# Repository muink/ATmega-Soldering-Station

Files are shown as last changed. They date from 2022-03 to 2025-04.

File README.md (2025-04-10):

## !!! Warning: the version with "t" is the test version, there may be stability problems! Not recommended for production environments
## !!! 警告：带有“t”的是测试版本，可能存在稳定性问题！不建议用于生产环境

# 1. Overview
T12 焊台控制器功能介绍
T12 Quick Heating Soldering Station featuring
- 烙铁头温度实时监测
- Temperature measurement of the tip
- PID温度控制
- Direct or PID control of the heater
- 可以通过编码器进行控制温度
- Temperature control via rotary encoder
- 短按编码器进入短时升温模式
- Boost mode by short pressing rotary encoder switch
- 长按编码器进入主菜单
- Setup menu by long pressing rotary encoder switch
- 手柄震动检测（需要手柄含有震动传感器）
- Handle movement detection (by checking ball switch)
- 烙铁上架检测（使用红外距离传感器）
- Handle docked detection (by IR distance sensor)
- 手柄连接检测（通过判断烙铁头温度是否能够被读取来实现）
- Iron unconnected detection (by idenfying invalid temperature readings)
- 定时器设定 - 随眠，关机时间
- Time driven sleep/power off mode if iron is unused (movement detection)
- 可以测量主控芯片电压以及温度
- Measurement of input voltage, Vcc and ATmega's internal temperature
- 在OLED上实现信息显示
- Information display on OLED
- 支持无源蜂鸣器
- Buzzer
- 允许设置不同烙铁头的温度校准值
- Calibrating and managing different soldering tips
- 设置被保存在EEPROM，掉电不丢失
- Storing user settings into the EEPROM
- 允许热插拔烙铁头，并弹出烙铁头配置选择菜单
- Tip change detection
- 支援 N-沟道和 P-沟道 MOS管
- Support for N-Channel and P-Channel MOSFETs
- 支持屏幕翻转
- Screen flip support
- 支持编码器反转
- Rotary encoder reverse support

## =========UI upgraded version =========

- 芯片过热以及低电压报警
- Chip overheating and low voltage alarm
- 更好的实时温度条以及实时功率条
- Better real-time temperature bar and real-time power bar
- 拥有过渡动画
- Have transition animation
- 内置屏幕保护程序
- Built in screen saver
- 屏幕翻转设置
- Screen flip settings
- 内置英文、中文语言包
- Built in English and Chinese language pack
- 开机密码设置
- System Password
- 允许设置旋钮方向
- Knob direction setting menu
- 内嵌看门狗，宕机自动重启
- Watchdog timer automatic reset the MCU

## V1.8t7 New features:

- EEPROM可用性检查机制
- EEPROM availability check

- 允许保存最大30个烙铁头的配置
- Tip change detection30 preservable soldering tip configurations

- 9段温度曲线拟合
- 9 segments of temperature curve fitting

## Links:
- Project Link: https://easyeda.com/dropair/z-solderingstation-smd-v2_copy
- Project Video (Orignal): https://youtu.be/I9ATDxvQ1Bc
- Video from John Glavinos (electronics4all): https://youtu.be/4YDcWfOQmz4
- Video from LHW-createskyblue (UI-v1.6L): https://b23.tv/LiOe54
- T245 version with P-channel MOSFET by TaaraLabs: https://taaralabs.eu/atmega-t245/

# 2. Versions, Upgrades and Notes

## Soldering Station v2.8:

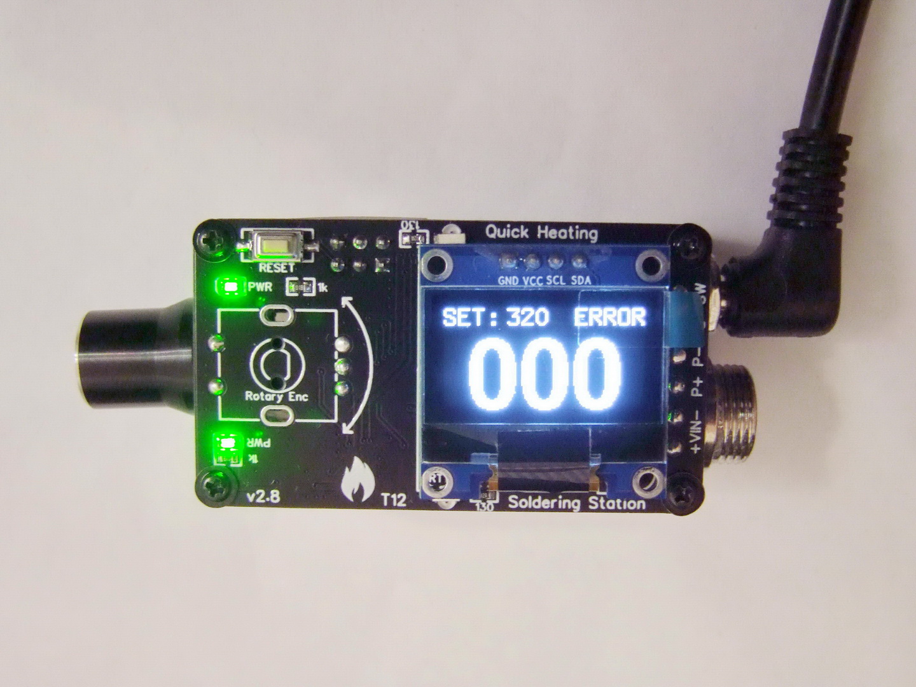
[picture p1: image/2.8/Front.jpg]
Front

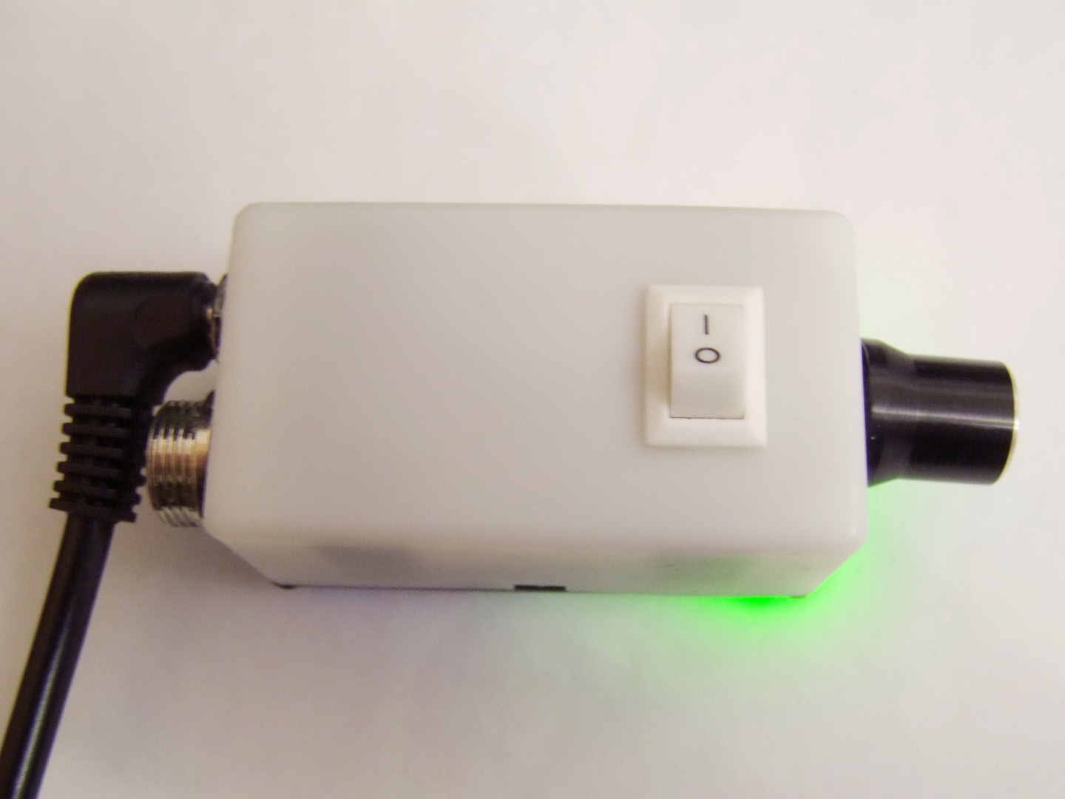
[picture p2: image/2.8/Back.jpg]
Back

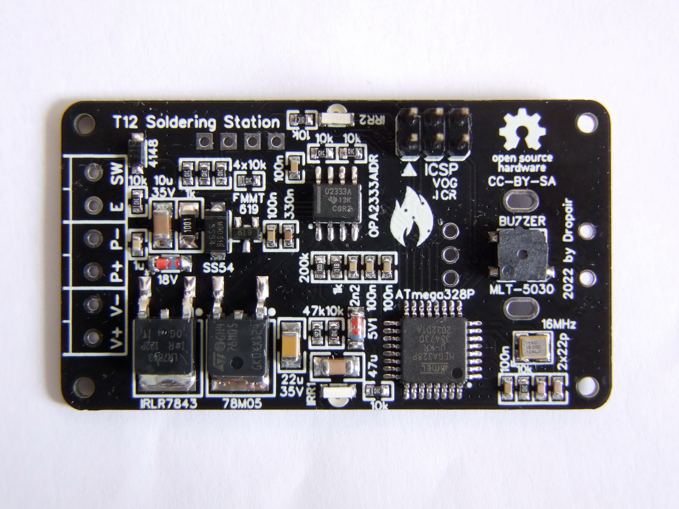
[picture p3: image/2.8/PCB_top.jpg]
PCB_Top

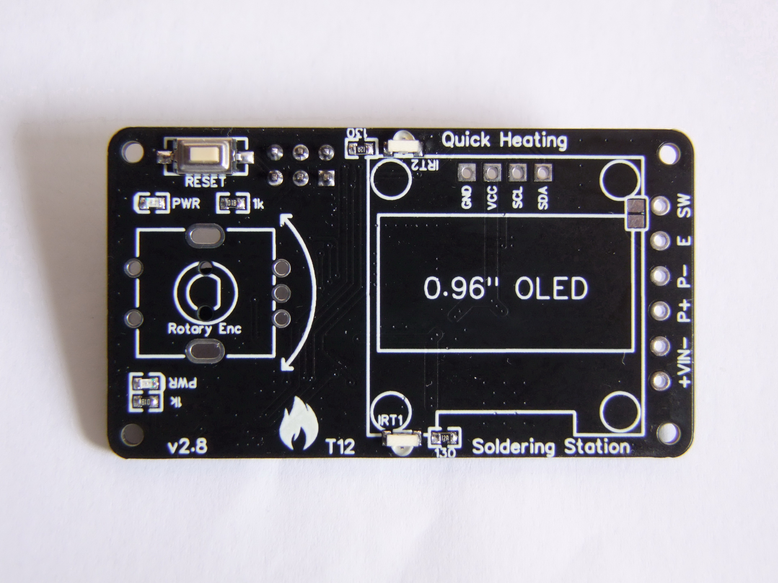
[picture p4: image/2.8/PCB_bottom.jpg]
PCB_Bottom

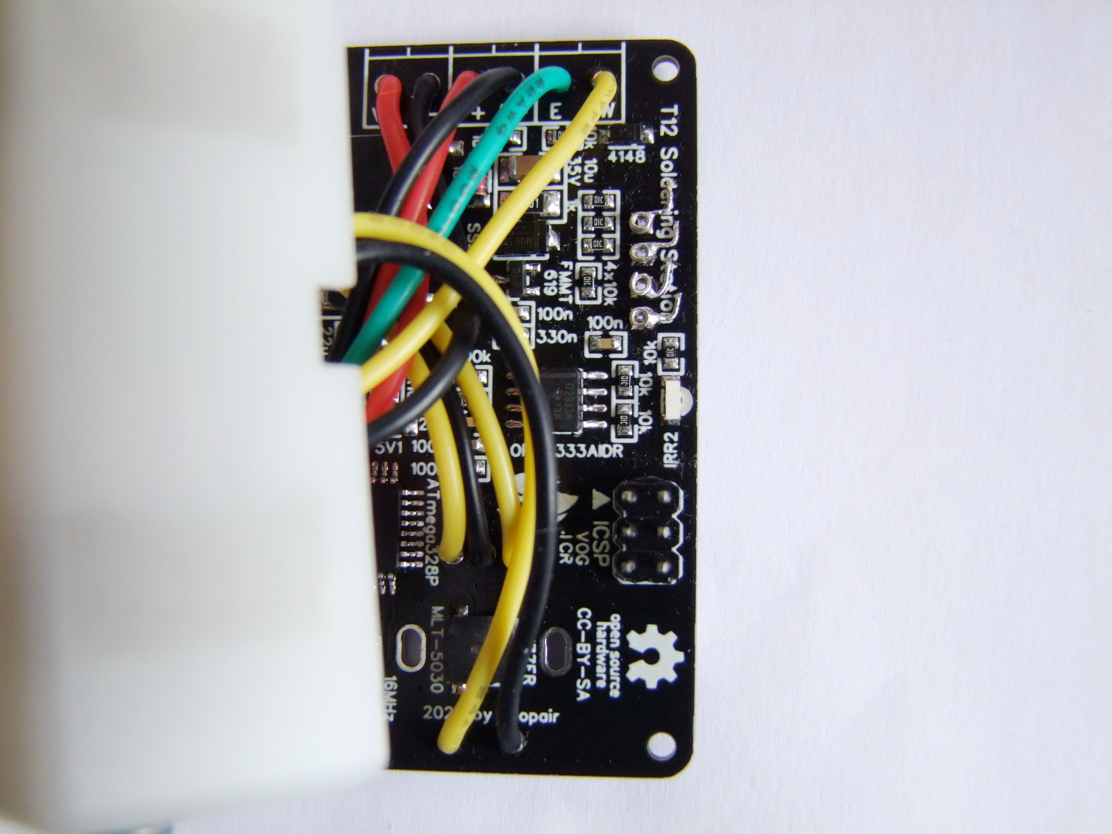
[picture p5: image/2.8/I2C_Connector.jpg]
I2C_Connector


## UI-V1.8t6 UI Upgrade by createskyblue & lihaoyun6



### Default control interface



### EEPROM availability check



### Tip menu



### 9 segments of temperature curve fitting & Soldering tip calibration page



### Temperature calibration coefficient



### Encoder direction regulation

Video from LHW-createskyblue (UI-v1.6L): https://b23.tv/LiOe54
	






## Notes and Errors

- In the board version 2.5 the diode D1 may overheat. To be on the safe side, the 18V zener diode D4 should be removed and the soldering station should be operated with a maximum of 20V. Alternatively, the diode D1 can be replaced with an SS54 schottky diode and the BJT Q1 with an FMMT619. 

# 3. Power Supply Specification Requirements #

Choose a power supply with an output voltage between 12V and 24V which can provide an output current according to the table below. The power supply must be well stabilized. The current and power is determined by the resistance (R = 8 Ohm) of the heater.

|Voltage (U)|Current (I) = U / R|Power (P) = U² / R|
|-|-|-|
|12 V|1.50 A|18 W|
|13 V|1.63 A|21 W|
|14 V|1.75 A|25 W|
|15 V|1.88 A|28 W|
|16 V|2.00 A|32 W|
|17 V|2.13 A|36 W|
|18 V|2.25 A|41 W|
|19 V|2.38 A|45 W|
|20 V|2.50 A|50 W|
|21 V|2.63 A|55 W|
|22 V|2.75 A|61 W|
|23 V|2.88 A|66 W|
|24 V|3.00 A|72 W|

# 4. Temperature Measurement and OpAmp Considerations #

A thermocouple (temperature sensor) is located in the T12 soldering tip. It creates a very small voltage depending on the temperature difference between the hot end and the cold junction (about 22 microvolts per degree Celsius). To measure this, the heater must be switched off since both share the same connections. The low voltage is amplified by the OpAmp and measured by the ADC of the microcontroller. The LMV358 is a very cheap and versatile OpAmp, but not the ideal choice for this task because it has a fairly high input offset voltage and is quite noisy. Although the SolderingStation also works with this OpAmp thanks to the software's smoothing and calibration algorithms, I highly recommend spending a little more money in a better one. The OPA2330AIDR or OPA2333AIDR for instance have the same pinout and can also be used with this board. They provide significantly more accurate and stable temperature measurements.






# 5. Heater High Side Switch with N-Channel MOSFET and Charge Pump #

The microcontroller switches the heater on and off via the MOSFET. Since the temperature measurement must be done over the same line and against ground, the MOSFET has to be placed between the supply voltage and the heater (high-side switch). A P-Channel MOSFET is normally used for this configuration. However, N-Channel MOSFETs usually have a lower resistance (RDS (on)), in the case of the IRLR7843 only 3 milliohms. A low resistance means a higher efficiency and a lower heat development of the MOSFET. For an N-channel MOSFET to function as a high-side switch, an additional circuit is required to maintain a positive GATE-TO-SOURCE voltage after the MOSFET is switched on. This is done using a so-called charge pump consisting of a capacitor and a diode. The principle of operation is illustrated in the following graphic by [Smallp Tsai](https://github.com/SmallpTsai):




# 6. Building Instructions #

In addition to the components for the PCB you will need the following:

- 3D-printed case ***1**
- SSD1306 0.96inch IC2 OLED ***1**
- EC11 Rotary encoder ***1**
- GX12-4P Aviator Plug ***1**
- DC-5.5*2.1 Power Jack ***1**
- KCD11 Rocker Switch ***1**
- 22AWG Wires(Red/Black/Green) **~~**
- 24AWG Wires(Black/Yellow) **~~**
- Heat Shrink Tube **~~**
- 20x10x2mm Neodymium Magnets ***4**
- M2x5mm Self-tapping screws ***4**

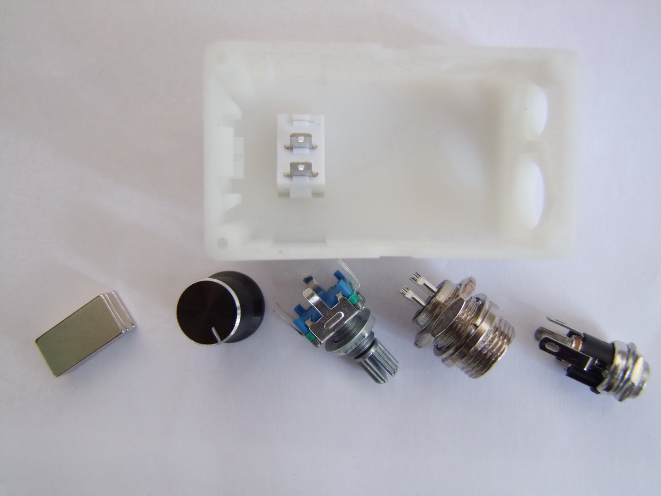
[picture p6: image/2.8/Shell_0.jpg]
Parts

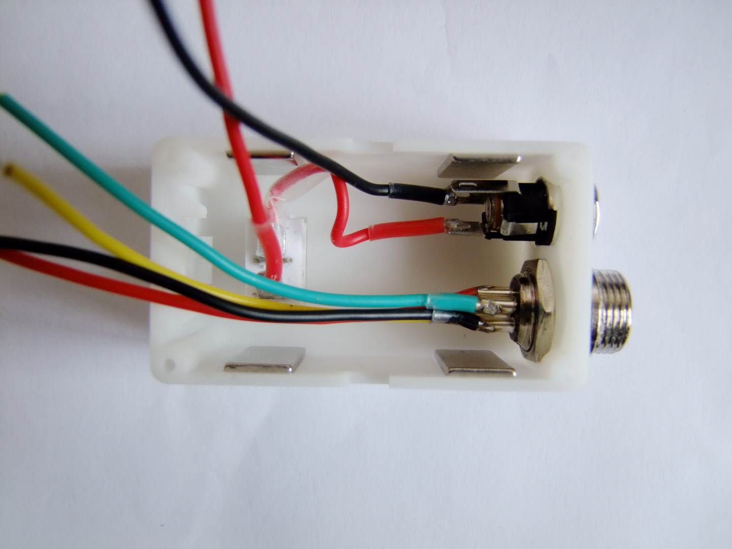
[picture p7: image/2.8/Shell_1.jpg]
Wire_Connection_1

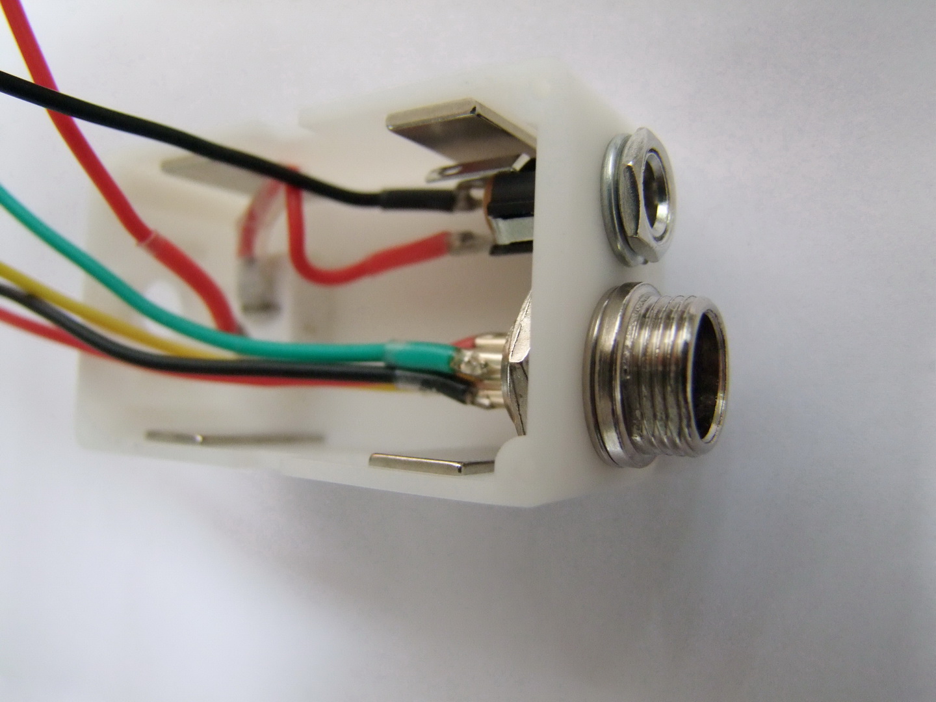
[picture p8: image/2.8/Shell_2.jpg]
Wire_Connection_2

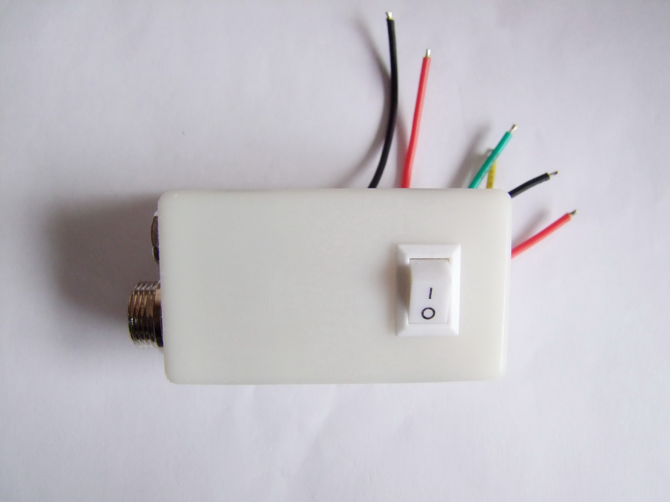
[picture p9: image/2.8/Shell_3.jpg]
Shell_3

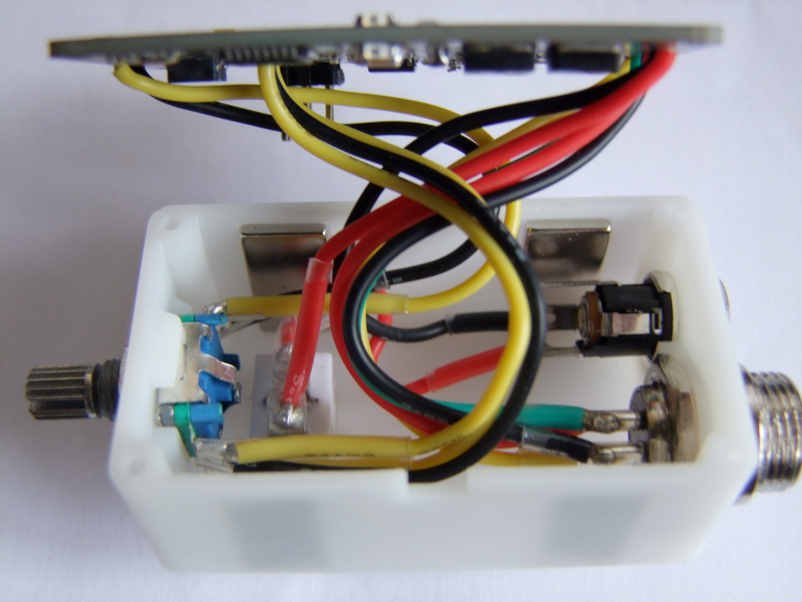
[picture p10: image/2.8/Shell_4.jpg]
AssemblyPCB


Make sure that all parts fit nicely into the case. Solder the wires to the connectors and protect them with heat shrinks. Use thick wires (AWG18) for the power connections. Make all connections according to the schematic down below but keep in mind, that there's no standard pinout. Solder the wires directly to the corresponding pads on the pcb. To make the soldering station ESD-safe, connect the earth (E) terminal of the aviator plug to a female dupont connector and glue it into the corresponding opening on the case. Now you can connect the soldering station via a male dupont connector to an earth terminal. Upload the firmware and screw the pcb on top of the case.



The pinout shown works for the [Quecoo handles from aliexpress](https://aliexpress.com/wholesale?SearchText=quecoo+handle). Different handles may have different pinouts. If you are assembling your handle yourself, follow the scheme shown below. The video by [John Glavinos (electronics4all)](https://www.youtube.com/watch?v=DcmiFfuZw38) shows how it's done.



# 7. License #



This work is licensed under Creative Commons Attribution-ShareAlike 3.0 Unported License. 
(http://creativecommons.org/licenses/by-sa/3.0/)

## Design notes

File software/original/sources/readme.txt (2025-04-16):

Libraries:
https://github.com/olikraus/u8glib
https://github.com/br3ttb/Arduino-PID-Library

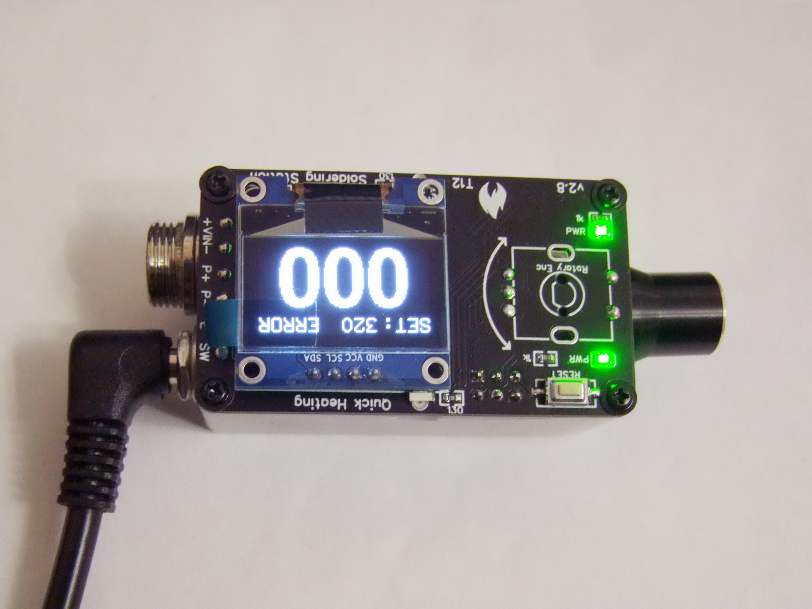
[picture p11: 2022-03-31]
image/2.8/Front_.jpg

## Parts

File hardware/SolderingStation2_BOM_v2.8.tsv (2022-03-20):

ID | Name | Designator | Footprint | Quantity | Manufacturer Part | Manufacturer | Supplier | Supplier Part
1 | MLT-5030 | BUZZER1 | MLT-5030 | 1 | MLT-5030 | HNDZ | LCSC | C95297
2 | 100n | C1,C2,C3,C9,C10 | 0603 | 5 | CL10B104KB8NNNC | SAMSUNG | LCSC | C1591
3 | 47u | C4 | 1206 | 1 | 1206X476M100NT | FH | LCSC | C96381
4 | 22p | C5,C6 | 0603 | 2 | CL10C220JB8NNNC | SAMSUNG | LCSC | C1653
5 | 10u | C7 | 1206 | 1 | CL31B106KBHNNNE | SAMSUNG | LCSC | C89632
6 | 2n2 | C8 | 0603 | 1 | CL10B222KB8NNNC | SAMSUNG | LCSC | C16033
7 | 330n | C11 | 0603 | 1 | C1608X7R1H334KT000E | TDK | LCSC | C76621
8 | 22u | C12 | 1206 | 1 | C3216X5R1V226MTJ00E | TDK | LCSC | C342620
9 | 1u | C13 | 0603 | 1 | CL10A105KB8NNNC | SAMSUNG | LCSC | C15849
10 | SS54 | D1 | DIODE-SMA(DO-214AC) | 1 | SS54 | Jingdao | LCSC | C123946
11 | 1N4148W | D2 | DIODE-SOD-123 | 1 | 1N4148W-E3-08 | Vishay Intertech | LCSC | C241939
12 | 5V1 | D3 | LL-34_L3.5-W1.5-RD | 1 | ZMM5V1 | SEMTECH | LCSC | C8061
13 | 18V | D4 | LL-34_L3.5-W1.5-RD | 1 | ZMM18 | SEMTECH | LCSC | C8071
14 | ICSP-6 | ICSP | ICSP-6 | 1 | ?
15 | PT12-21C/TR8 | IRR1,IRR2 | SENSOR-SMD_L3.0-W2.0-RD | 2 | PT12-21C/TR8 | EVERLIGHT | LCSC | C53674
16 | IR12-21C/TR8 | IRT1,IRT2 | SENSOR-SMD_IR12-21C-TR8 | 2 | IR12-21C/TR8 | EVERLIGHT | LCSC | C53672
17 | PWR | LED1,LED2 | LED0603 | 2 | 19-217/BHC-ZL1M2RY/3T | EVERLIGHT | LCSC | C72041
18 | OLED | OLED | I2C - OLED 0.96" 128X64 | 1 | SSD1306 I2C OLED
19 | KF350-3.5mm | P1,P2,P3 | KF350-2P | 3 | WJ2EDGVC-5.08-2P | ReliaPro | LCSC | C8445
20 | FMMT619 | Q1 | SOT-23-3_L2.9-W1.6-P1.90-LS2.8-BR | 1 | FMMT619 | CJ | LCSC | C53071
21 | IRLR7843TRPBF | Q2 | TO-252-2 | 1 | IRLR7843TRPBF | IR | LCSC | C21988
22 | 10k | R1,R3,R4,R6,R7,R10,R11,R13,R14,R15,R17 | 0603 | 11 | 0603WAF1002T5E | UniOhm | LCSC | C25804
23 | 1k | R2,R9,R19 | 0603 | 3 | 0603WAF1001T5E | UniOhm | LCSC | C21190
24 | 1k | R5 | 1206 | 1 | 1206W4F1001T5E | UniOhm | LCSC | C4410
25 | 200k | R8 | 0603 | 1 | 0603WAF2003T5E | UniOhm | LCSC | C25811
26 | 47k | R12 | 0603 | 1 | 0603WAF4702T5E | UniOhm | LCSC | C25819
27 | 130 | R16,R18 | 0603 | 2 | 0603WAF1300T5E | UniOhm | LCSC | C22796
28 | 3x6x2.5 | RESET | KEY-3.0*6.0 | 1 | 3x6x2.5Red head high temperature | ReliaPro | LCSC | C46491
29 | SOLDERJUMPER | SJ1 | SOLDERJUMPER | 1
30 | Rotary Enc | SW1 | BOURNS_PEC11R-4XXXF-SXXXX | 1 | PEC11R-4015F-S0024 | BOURNS | LCSC | C143789
31 | ATMEGA328P-AU | U1 | TQFP-32_7X7X08P | 1 | ATMEGA328P-AU | MICROCHIP | LCSC | C14877
32 | 78M05 | U2 | TO-252-2 | 1 | L78M05CDT-TR | STMicroelectronics | LCSC | C55509
33 | LMV358IDR | U3 | SOP-8_150MIL | 1 | LMV358IDR | TI | LCSC | C63813
34 | 16MHz | X1 | OSC-SMD_4P-L3.2-W2.5-BL | 1 | X322516MLB4SI | YXC | LCSC | C13738

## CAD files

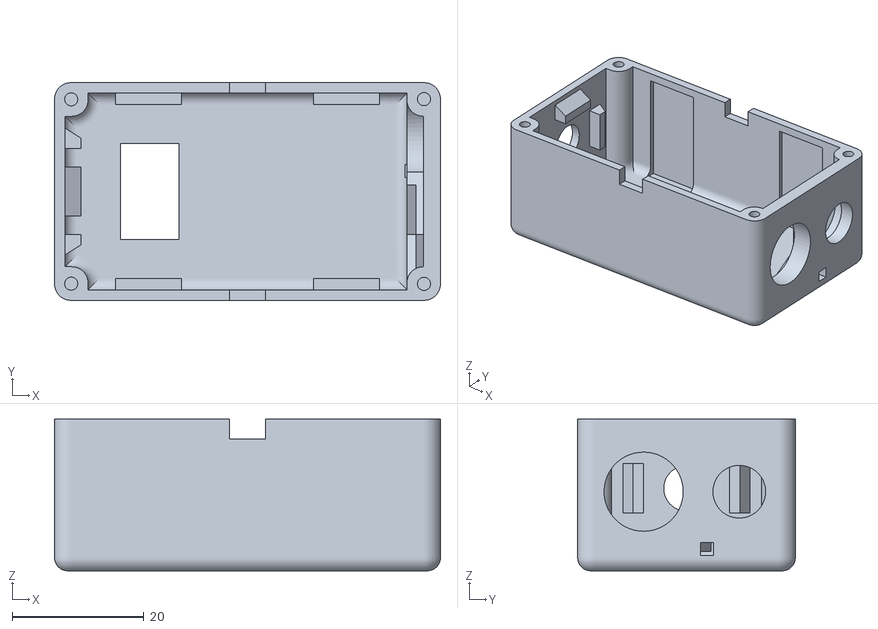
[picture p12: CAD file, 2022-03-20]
3dprint/SolderungStationV2_Case_ESD_v2.8.stl
58.5 x 33.0 x 23.0

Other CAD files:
3dprint/SolderungStationV2_Case_ESD_v2.8.f3d

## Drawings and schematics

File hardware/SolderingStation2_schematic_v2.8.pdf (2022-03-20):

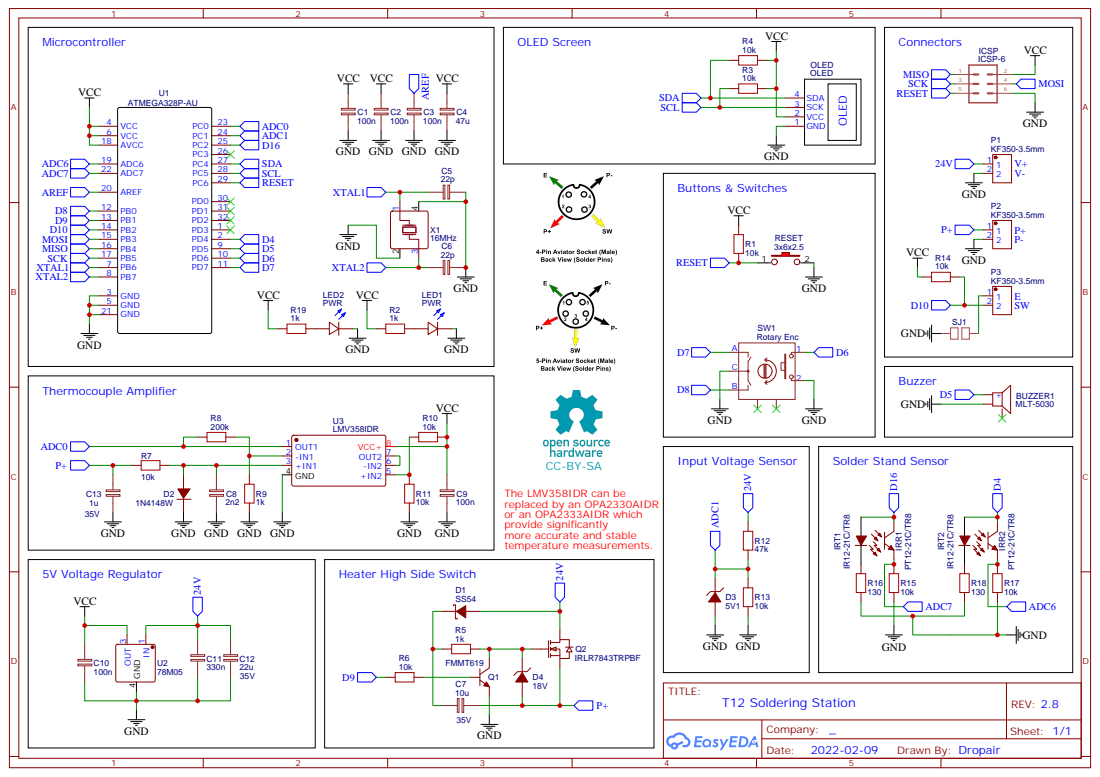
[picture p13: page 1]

GND GND

The LMV358IDR can be
replaced by an OPA2330AIDR
or an OPA2333AIDR which
provide significantly
more accurate and stable
temperature measurements.

Heater High Side Switch

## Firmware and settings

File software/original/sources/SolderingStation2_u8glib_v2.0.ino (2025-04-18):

// SolderingStation2
//
// ATmega328-controlled Soldering Station for Hakko T12 Tips.
//
// This version of the code implements:
// - Temperature measurement of the tip
// - Direct or PID control of the heater
// - Temperature control via rotary encoder
// - Boost mode by short pressing rotary encoder switch
// - Setup menu by long pressing rotary encoder switch
// - Handle movement detection (by checking ball switch)
// - Handle docked detection (by IR distance sensor)
// - Iron unconnected detection (by idenfying invalid temperature readings)
// - Time driven sleep/power off mode if iron is unused (movement detection)
// - Measurement of input voltage, Vcc and ATmega's internal temperature
// - Information display on OLED
// - Buzzer
// - Calibrating and managing different soldering tips
// - Storing user settings into the EEPROM
// - Tip change detection
// - Can be used with either N or P channel mosfets
// - Screen flip support
// - Rotary encoder reverse support
//
// Power supply should be in the range of 16V/2A to 24V/3A and well
// stabilized.
//
// For calibration you need a soldering iron tips thermometer. For best results
// wait at least three minutes after switching on the soldering station before 
// you start the calibration process.
//
// Controller:  ATmega328p
// Core:        Barebones ATmega (https://github.com/carlosefr/atmega)
// Clockspeed:  16 MHz external
//
// It is recommended not to use a bootloader!
//
// Thank you for the code contributions:
// - John Glavinos, https://youtu.be/4YDcWfOQmz4
// - createskyblue, https://github.com/createskyblue
// - TaaraLabs, https://github.com/TaaraLabs
// - muink, https://github.com/muink
//
// 2019 - 2022 by Stefan Wagner
// Project Files (EasyEDA): https://easyeda.com/wagiminator
// Project Files (Github):  https://github.com/wagiminator
// License: http://creativecommons.org/licenses/by-sa/3.0/
//
// 2022 - 2025 by dropair & muink
// Project Files (EasyEDA): https://easyeda.com/dropair/z-solderingstation-smd-v2_copy
// Project Files (Github):  https://github.com/muink/ATmega-Soldering-Station
// License: http://creativecommons.org/licenses/by-sa/3.0/


// Libraries
#include <U8glib.h>             // https://github.com/olikraus/u8glib
#include <PID_v1.h>             // https://github.com/wagiminator/ATmega-Soldering-Station/blob/master/software/libraries/Arduino-PID-Library.zip 
                                // (old cpp version of https://github.com/mblythe86/C-PID-Library/tree/master/PID_v1)
#include <EEPROM.h>             // for storing user settings into EEPROM
#include <avr/sleep.h>          // for sleeping during ADC sampling

// Hardware version
#define HWVERSION     "v2.8"

// Firmware version
#define VERSION       "v2.0"

// Type of MOSFET
#define N_MOSFET                // P_MOSFET or N_MOSFET

// Type of OLED Controller
#define SSD1306                 // SSD1306 or SH1106

// Type of rotary encoder
#define ROTARY_TYPE   1         // 0: 2 increments/step; 1: 4 increments/step (default)

// Pins
#define SENSOR_PIN    A0        // tip temperature sense
#define VIN_PIN       A1        // input voltage sense
#define BUZZER_PIN     5        // buzzer
#define BUTTON_PIN     6        // rotary encoder switch
#define ROTARY_1_PIN   7        // rotary encoder 1
#define ROTARY_2_PIN   8        // rotary encoder 2
#define CONTROL_PIN    9        // heater MOSFET PWM control
#define SWITCH_PIN    10        // handle vibration switch

// IR sensor Pins
#define DOCKDETT_PIN  A6        // IR sensor (top) (screen flipped)
#define DOCKDETB_PIN  A7        // IR sensor (bottom)
#define IRPOWT_PIN     4        // IR sensor power supply (top) (screen flipped)
#define IRPOWB_PIN    16        // IR sensor power supply (bottom)

// Default temperature control values (recommended soldering temperature: 300-380°C)
#define TEMP_MIN      150       // min selectable temperature
#define TEMP_MAX      400       // max selectable temperature
#define TEMP_DEFAULT  280       // default start setpoint
#define TEMP_SLEEP    150       // temperature in sleep mode
#define TEMP_BOOST     50       // temperature increase in boost mode
#define TEMP_STEP      10       // rotary encoder temp change steps

// Default tip temperature calibration values
#define TEMP200       220       // temperature at ADC = 200
#define TEMP280       300       // temperature at ADC = 280
#define TEMP360       388       // temperature at ADC = 360
#define TEMPCHP       30        // chip temperature while calibration
#define INTEMPOFF     77        // internal temperature offset values
#define TIPMAX        8         // max number of tips
#define TIPNAMELENGTH 6         // max length of tip names (including termination)
#define TIPNAME       "HAKKO"   // default tip name

// Default timer values (0 = disabled)
#define TIME2SLEEP     5        // time to enter sleep mode in minutes
#define TIME2OFF      15        // time to shut off heater in minutes
#define TIMEOFBOOST   40        // time to stay in boost mode in seconds

// Default handle docked distance values (0 = disabled)
#define DOCKINDISTANCE 12       // judgment value of handle docked. the closer the handle is, the higher the value
#define DOCKINBITDEPTH 11       // IR sensor sampling depth. allowed values: 10-12

// Control values
#define TIME2SETTLE   950       // time in microseconds to allow OpAmp output to settle
#define SMOOTHIE      0.05      // OpAmp output smooth factor (1=no smoothing; 0.05 default)
#define PID_ENABLE    false     // enable PID control
#define BEEP_ENABLE   true      // enable/disable buzzer
#define BODYFLIP      false     // enable/disable screen flip
#define ECREVERSE     false     // enable/disable rotary encoder reverse
#define MAINSCREEN    0         // type of main screen (0: big numbers; 1: more infos)

// EEPROM identifier
#define EEPROM_IDENT  0xE76C   // to identify if EEPROM was written by this program

// MOSFET control definitions
#if defined (P_MOSFET)         // P-Channel MOSFET
  #define HEATER_ON   255
  #define HEATER_OFF  0
  #define HEATER_PWM  255 - Output
#elif defined (N_MOSFET)       // N-Channel MOSFET
  #define HEATER_ON   0
  #define HEATER_OFF  255
  #define HEATER_PWM  Output
#else
  #error Wrong MOSFET type!
#endif

// Define the aggressive and conservative PID tuning parameters
double aggKp=11, aggKi=0.5, aggKd=1;
double consKp=11, consKi=3, consKd=5;

// Default values that can be changed by the user and stored in the EEPROM
uint16_t  DefaultTemp = TEMP_DEFAULT;
uint16_t  SleepTemp   = TEMP_SLEEP;
uint8_t   BoostTemp   = TEMP_BOOST;
int16_t   InTempOff   = INTEMPOFF;
uint8_t   time2sleep  = TIME2SLEEP;
uint8_t   time2off    = TIME2OFF;
uint8_t   timeOfBoost = TIMEOFBOOST;
uint8_t   DockinDistance = DOCKINDISTANCE;
uint8_t   MainScrType = MAINSCREEN;
bool      PIDenable   = PID_ENABLE;
bool      beepEnable  = BEEP_ENABLE;
bool      BodyFlip    = BODYFLIP;
bool      ECReverse   = ECREVERSE;

// Default values for tips
uint16_t  CalTemp[TIPMAX][4] = {TEMP200, TEMP280, TEMP360, TEMPCHP};
char      TipName[TIPMAX][TIPNAMELENGTH] = {TIPNAME};
uint8_t   CurrentTip   = 0;
uint8_t   NumberOfTips = 1;

// Menu items
const char *SetupItems[]       = { "Setup Menu", "Tip Settings", "Temp Settings",
                                   "Timer Settings", "Dock Settings", "Control Type", "Main Screen",
                                   "Buzzer", "Screen Flip", "EC Reverse", "Information", "Return" };
const char *TipItems[]         = { "Tip:", "Change Tip", "Calibrate Tip", 
                                   "Rename Tip", "Delete Tip", "Add new Tip", "Return" };
const char *TempItems[]        = { "Temp Settings", "Default Temp", "Sleep Temp", 
                                   "Boost Temp", "Return" };
const char *TimerItems[]       = { "Timer Settings", "Sleep Timer", "Off Timer", 
                                   "Boost Timer", "Return" };
const char *ControlTypeItems[] = { "Control Type", "Direct", "PID" };
const char *MainScreenItems[]  = { "Main Screen", "Big Numbers", "More Infos" };
const char *StoreItems[]       = { "Store Settings ?", "No", "Yes" };
const char *SureItems[]        = { "Are you sure ?", "No", "Yes" };
const char *BuzzerItems[]      = { "Buzzer", "Disable", "Enable" };
const char *FlipItems[]        = { "Screen Flip", "Disable", "Enable" };
const char *ECReverseItems[]   = { "EC Reverse", "Disable", "Enable" };
const char *DefaultTempItems[] = { "Default Temp", "\xB0""C" };
const char *SleepTempItems[]   = { "Sleep Temp", "\xB0""C" };
const char *BoostTempItems[]   = { "Boost Temp", "\xB0""C" };
const char *SleepTimerItems[]  = { "Sleep Timer", "Minutes" };
const char *OffTimerItems[]    = { "Off Timer", "Minutes" };
const char *BoostTimerItems[]  = { "Boost Timer", "Seconds" };
const char *DistanceItems[]    = { "Set Distance", "\x4A" };
const char *DeleteMessage[]    = { "Warning", "You cannot", "delete your", "last tip!" };
const char *MaxTipMessage[]    = { "Warning", "You reached", "maximum number", "of tips!" };

// Variables for pin change interrupt
volatile uint8_t  a0, b0, c0, d0;
volatile bool     ab0;
volatile int      count, countMin, countMax, countStep;
volatile bool     handleMoved, handleDocked = true;
 
// Variables for temperature control
uint16_t  SetTemp, ShowTemp, gap, Step;
double    Input, Output, Setpoint, RawTemp, CurrentTemp, ChipTemp;

// Variables for voltage readings
uint16_t  Vcc, Vin;

// Variables for IR sensor
uint16_t  envLight;
int       lastDist;
 
// State variables
bool      inSleepMode = false;
bool      inOffMode   = false;
bool      inBoostMode = false;
bool      inCalibMode = false;
bool      isWorky     = true;
bool      beepIfWorky = true;
bool      TipIsPresent= true;

// Timing variables
uint32_t  sleepmillis;
uint32_t  boostmillis;
uint32_t  buttonmillis;
uint8_t   goneMinutes;
uint8_t   goneSeconds;
uint8_t   SensorCounter = 255;

// Specify variable pointers and initial PID tuning parameters
PID ctrl(&Input, &Output, &Setpoint, aggKp, aggKi, aggKd, REVERSE);
 
// Setup u8g object depending on OLED controller
#if defined (SSD1306)
  U8GLIB_SSD1306_128X64 u8g(U8G_I2C_OPT_DEV_0|U8G_I2C_OPT_NO_ACK|U8G_I2C_OPT_FAST);
#elif defined (SH1106)
  U8GLIB_SH1106_128X64 u8g(U8G_I2C_OPT_FAST|U8G_I2C_OPT_NO_ACK);
#else
  #error Wrong OLED controller type!
#endif

// Declare the denoiseAnalog function
uint16_t denoiseAnalog (byte port, uint8_t analog_deep = 10);


void setup() { 
  // set the pin modes
  pinMode(SENSOR_PIN,   INPUT);
  pinMode(VIN_PIN,      INPUT);
  pinMode(DOCKDETB_PIN, INPUT);
  pinMode(DOCKDETT_PIN, INPUT);
  pinMode(IRPOWB_PIN,   OUTPUT);
  pinMode(IRPOWT_PIN,   OUTPUT);
  pinMode(BUZZER_PIN,   OUTPUT);
  pinMode(CONTROL_PIN,  OUTPUT);
  pinMode(ROTARY_1_PIN, INPUT_PULLUP);
  pinMode(ROTARY_2_PIN, INPUT_PULLUP);
  pinMode(BUTTON_PIN,   INPUT_PULLUP);
  pinMode(SWITCH_PIN,   INPUT_PULLUP);
  
  analogWrite(CONTROL_PIN, HEATER_OFF); // this shuts off the heater
  digitalWrite(IRPOWB_PIN, LOW);        // must be LOW when IR sensor not in use
  digitalWrite(IRPOWT_PIN, LOW);        // must be LOW when IR sensor not in use
  digitalWrite(BUZZER_PIN, LOW);        // must be LOW when buzzer not in use

  // setup ADC
  ADCSRA |= bit (ADPS0) | bit (ADPS1) | bit (ADPS2);  // set ADC prescaler to 128
  ADCSRA |= bit (ADIE);                 // enable ADC interrupt
  interrupts ();                        // enable global interrupts

  // setup pin change interrupt for rotary encoder
  PCMSK0 = bit (PCINT0);                // Configure pin change interrupt on Pin8
  PCICR  = bit (PCIE0);                 // Enable pin change interrupt
  PCIFR  = bit (PCIF0);                 // Clear interrupt flag

  // prepare and start OLED
  if      ( u8g.getMode() == U8G_MODE_R3G3B2 )   u8g.setColorIndex(255);
  else if ( u8g.getMode() == U8G_MODE_GRAY2BIT ) u8g.setColorIndex(3);
  else if ( u8g.getMode() == U8G_MODE_BW )       u8g.setColorIndex(1);
  else if ( u8g.getMode() == U8G_MODE_HICOLOR )  u8g.setHiColorByRGB(255,255,255);

  // get default values from EEPROM
  getEEPROM();

  // set screen flip
  SetFlip();

  // enable IR senor
  SetIR();

  // read supply voltages in mV
  Vcc = getVCC(); Vin = getVIN();

  // read the value of ambient light from IR sensor
  envLight = getHandleLight(); lastDist = 0;

  // read and set current iron temperature
  SetTemp  = DefaultTemp;
  RawTemp  = denoiseAnalog(SENSOR_PIN);
  ChipTemp = getChipTemp();
  calculateTemp();

  // turn on heater if iron temperature is well below setpoint
  if ((CurrentTemp + 20) < DefaultTemp) analogWrite(CONTROL_PIN, HEATER_ON);

  // set PID output range and start the PID
  ctrl.SetOutputLimits(0, 255);
  ctrl.SetMode(AUTOMATIC);

  // set initial rotary encoder values
  a0 = PINB & 1; b0 = PIND>>7 & 1; ab0 = (a0 == b0);
  setRotary(TEMP_MIN, TEMP_MAX, TEMP_STEP, DefaultTemp);
  
  // reset sleep timer
  sleepmillis = millis();

  // long beep for setup completion
  beep(); beep();
}
 

void loop() {
  ROTARYCheck();      // check rotary encoder (temp/boost setting, enter setup menu)
  SLEEPCheck();       // check and activate/deactivate sleep modes
  SENSORCheck();      // reads temperature and vibration switch of the iron
  Thermostat();       // heater control
  MainScreen();       // updates the main page on the OLED
}




// check rotary encoder; set temperature, toggle boost mode, enter setup menu accordingly
void ROTARYCheck() {
  // set working temperature according to rotary encoder value
  SetTemp = getRotary();
  
  // check rotary encoder switch
  uint8_t c = digitalRead(BUTTON_PIN);
  if ( !c && c0 ) {
    beep();
    buttonmillis = millis();
    while( (!digitalRead(BUTTON_PIN)) && ((millis() - buttonmillis) < 500) );
    if ((millis() - buttonmillis) >= 500) SetupScreen();
    else {
      inBoostMode = handleDocked ? false : !inBoostMode;
      if (inBoostMode) boostmillis = millis();
      handleMoved = true;
    }
  }
  c0 = c;

  // check timer when in boost mode
  if (inBoostMode && timeOfBoost) {
    goneSeconds = (millis() - boostmillis) / 1000;
    if (goneSeconds >= timeOfBoost) {
      inBoostMode = false;              // stop boost mode
      beep();                           // beep if boost mode is over
      beepIfWorky = true;               // beep again when working temperature is reached
    }
  }
}


// check and activate/deactivate sleep modes
void SLEEPCheck() {
  if (handleMoved) {                    // if handle was moved
    if (inSleepMode && !handleDocked) { // in sleep or off mode? and not docked (ready to work)
      if ((CurrentTemp + 20) < SetTemp) // if temp is well below setpoint
        analogWrite(CONTROL_PIN, HEATER_ON);    // then start the heater right now
      beep();                           // beep on wake-up
      beepIfWorky = true;               // beep again when working temperature is reached
    inSleepMode = false;                // reset sleep flag
    }
    handleMoved = false;                // reset handleMoved flag
    inOffMode   = false;                // reset off flag
    sleepmillis = millis();             // reset sleep timer
  }

  // check time passed since the handle was moved
  goneMinutes = (millis() - sleepmillis) / 60000;
  handleDocked = Docking();
  if ( (!inSleepMode) && ( ((time2sleep > 0) && (goneMinutes >= time2sleep)) || handleDocked ) ) {inSleepMode = true; inBoostMode = false; beep();}
  if ( (!inOffMode)   && (time2off   > 0) && (goneMinutes >= time2off  ) ) {inOffMode   = true; beep();}
}


// reads temperature, vibration switch and supply voltages
void SENSORCheck() {
  analogWrite(CONTROL_PIN, HEATER_OFF);       // shut off heater in order to measure temperature
  delayMicroseconds(TIME2SETTLE);             // wait for voltage to settle
  
  double temp = denoiseAnalog(SENSOR_PIN);    // read ADC value for temperature
  uint8_t d = digitalRead(SWITCH_PIN);        // check handle vibration switch
  if (d != d0) {handleMoved = true; d0 = d;}  // set flag if handle was moved
  if (! SensorCounter--) Vin = getVIN();      // get Vin every now and then
  
  analogWrite(CONTROL_PIN, HEATER_PWM);       // turn on again heater
  
  RawTemp += (temp - RawTemp) * SMOOTHIE;     // stabilize ADC temperature reading
  calculateTemp();                            // calculate real temperature value

  // stabilize displayed temperature when around setpoint
  if ((ShowTemp != Setpoint) || (abs(ShowTemp - CurrentTemp) > 5)) ShowTemp = CurrentTemp;
  if (abs(ShowTemp - Setpoint) <= 1) ShowTemp = Setpoint;

  // set state variable if temperature is in working range; beep if working temperature was just reached
  gap = abs(SetTemp - CurrentTemp);
  if (gap < 5) {
    if (!isWorky && beepIfWorky) beep();
    isWorky = true;
    beepIfWorky = false;
  }
  else isWorky = false;

  // checks if tip is present or currently inserted
  if (ShowTemp > 500) TipIsPresent = false;   // tip removed ?
  if (!TipIsPresent && (ShowTemp < 500)) {    // new tip inserted ?
    analogWrite(CONTROL_PIN, HEATER_OFF);     // shut off heater
    beep();                                   // beep for info
    TipIsPresent = true;                      // tip is present now
    ChangeTipScreen();                        // show tip selection screen
    updateEEPROM();                           // update setting in EEPROM
    handleMoved = true;                       // reset all timers
    RawTemp  = denoiseAnalog(SENSOR_PIN);     // restart temp smooth algorithm
    c0 = LOW;                                 // switch must be released
    setRotary(TEMP_MIN, TEMP_MAX, TEMP_STEP, SetTemp);  // reset rotary encoder
  }
}


// calculates real temperature value according to ADC reading and calibration values
void calculateTemp() {
  if      (RawTemp < 200) CurrentTemp = map (RawTemp,   0, 200,                     21, CalTemp[CurrentTip][0]);
  else if (RawTemp < 280) CurrentTemp = map (RawTemp, 200, 280, CalTemp[CurrentTip][0], CalTemp[CurrentTip][1]);
  else                    CurrentTemp = map (RawTemp, 280, 360, CalTemp[CurrentTip][1], CalTemp[CurrentTip][2]);
}


// controls the heater
void Thermostat() {
  // define Setpoint acoording to current working mode
  if      (inOffMode)   Setpoint = 0;
  else if (inSleepMode) Setpoint = SleepTemp;
  else if (inBoostMode) Setpoint = SetTemp + BoostTemp;
  else                  Setpoint = SetTemp; 

  // control the heater (PID or direct)
  gap = abs(Setpoint - CurrentTemp);
  if (PIDenable) {
    Input = CurrentTemp;
    if (gap < 30) ctrl.SetTunings(consKp, consKi, consKd);
    else ctrl.SetTunings(aggKp, aggKi, aggKd); 
    ctrl.Compute();
  } else {
    // turn on heater if current temperature is below setpoint
    if ((CurrentTemp + 0.5) < Setpoint) Output = 0; else Output = 255;
  }
  analogWrite(CONTROL_PIN, HEATER_PWM);     // set heater PWM
}


// creates a short beep on the buzzer
void beep(){
  if (beepEnable) {
    for (uint8_t i=0; i<255; i++) {
      digitalWrite(BUZZER_PIN, HIGH);
      delayMicroseconds(125);
      digitalWrite(BUZZER_PIN, LOW);
      delayMicroseconds(125);
    }
  }
}


// sets start values for rotary encoder
void setRotary(int rmin, int rmax, int rstep, int rvalue) {
  countMin  = rmin << ROTARY_TYPE;
  countMax  = rmax << ROTARY_TYPE;
  countStep = ECReverse ? -rstep : rstep;
  count     = rvalue << ROTARY_TYPE;  
}


// reads current rotary encoder value
int getRotary() {
  return (count >> ROTARY_TYPE);
}


// reads user settings from EEPROM; if EEPROM values are invalid, write defaults
void getEEPROM() {
  uint16_t identifier = (EEPROM.read(0) << 8) | EEPROM.read(1);
  if (identifier == EEPROM_IDENT) {
    DefaultTemp = (EEPROM.read(2) << 8) | EEPROM.read(3);
    SleepTemp   = (EEPROM.read(4) << 8) | EEPROM.read(5);
    BoostTemp   =  EEPROM.read(6);
    time2sleep  =  EEPROM.read(7);
    time2off    =  EEPROM.read(8);
    timeOfBoost =  EEPROM.read(9);
    DockinDistance = EEPROM.read(10);
    MainScrType =  EEPROM.read(11);
    PIDenable   =  EEPROM.read(12);
    beepEnable  =  EEPROM.read(13);
    BodyFlip    =  EEPROM.read(14);
    ECReverse   =  EEPROM.read(15);
    CurrentTip  =  EEPROM.read(16);
    NumberOfTips = EEPROM.read(17);

    uint8_t i, j;
    uint16_t counter = 18;
    for (i = 0; i < NumberOfTips; i++) {
      for (j = 0; j < TIPNAMELENGTH; j++) {
        TipName[i][j] = EEPROM.read(counter++);
      }
      for (j = 0; j < 4; j++) {
        CalTemp[i][j]  = EEPROM.read(counter++) << 8;
        CalTemp[i][j] |= EEPROM.read(counter++);
      }
    }
  }
  else {
    EEPROM.update(0, EEPROM_IDENT >> 8); EEPROM.update(1, EEPROM_IDENT & 0xFF);
    updateEEPROM();
  }
}


// writes user settings to EEPROM using updade function to minimize write cycles
void updateEEPROM() {
  EEPROM.update( 2, DefaultTemp >> 8);
  EEPROM.update( 3, DefaultTemp & 0xFF);
  EEPROM.update( 4, SleepTemp >> 8);
  EEPROM.update( 5, SleepTemp & 0xFF);
  EEPROM.update( 6, BoostTemp);
  EEPROM.update( 7, time2sleep);
  EEPROM.update( 8, time2off);
  EEPROM.update( 9, timeOfBoost);
  EEPROM.update(10, DockinDistance);
  EEPROM.update(11, MainScrType);
  EEPROM.update(12, PIDenable);
  EEPROM.update(13, beepEnable);
  EEPROM.update(14, BodyFlip);
  EEPROM.update(15, ECReverse);
  EEPROM.update(16, CurrentTip);
  EEPROM.update(17, NumberOfTips);

  uint8_t i, j;
  uint16_t counter = 18;
  for (i = 0; i < NumberOfTips; i++) {
    for (j = 0; j < TIPNAMELENGTH; j++) EEPROM.update(counter++, TipName[i][j]);
    for (j = 0; j < 4; j++) {
      EEPROM.update(counter++, CalTemp[i][j] >> 8);
      EEPROM.update(counter++, CalTemp[i][j] & 0xFF);
    }
  }
}


// check state and flip screen
void SetFlip() {
  if (BodyFlip) u8g.setRot180();
  else          u8g.undoRotation();
}
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

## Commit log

2022-03-20 hardware v2.8
    [SolderingStation2_BOM_v2.8.tsv, SolderungStationV2_Case_ESD_v2.8.f3d, SolderungStationV2_Case_ESD_v2.8.stl]
2025-04-16 fix and improve the accuracy of getChipTemp
    [SolderingStation2_u8glib_v2.0.ino]
2025-04-16 Added default tip temperature calibration for HAKKO
2025-04-18 define and initialize the Handle docked sensor
2025-04-18 Correction for internal temperature
    [SolderingStation2_u8glib_v2.0.ino]
